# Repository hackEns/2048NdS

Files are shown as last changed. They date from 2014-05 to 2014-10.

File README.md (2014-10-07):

Nuit des Sciences 2014
======================

Codes, schematics etc. pour l'installation de LEDs (montage Ledhill) pour la Nuit des Sciences 2014 à l'Ens.

# Structure

* `frontend/`: web interface for playing, customized 2048 game to be used as a controller for the game server.
* `leds/`: code running on the ATmega on the LEDs PCB.
* `pc_control/`: python scripts to send instructions to the LEDs.
* `tests/`: various tests files for both the PCBs and the Serial comm in Python.

# Usage

* Launch `test_order.py` in the `tests` folder, to get the correct order in which LEDs should be controlled.
* Put the output of the previous command in the `get_linear_led_number` function in `pc_control/game.py` line 98 to set the correct order for the LEDs.
* Set the correct controller at the top of `pc_control/game.py`.
* Launch `leds_server.py` in the `pc_control` folder, on the computer connected to the LEDs using a USB FTDI cable. Pass the device `/dev/ttyUSB*` used to communicate with the LEDs as argument.
* Launch `game.py` in the `pc_control` folder passing it the server ip address as first argument. This can be launched on any computer as long as it can communicate with the previous one _via_ the port 4242 (or any other port, if you update the files `game.py` and `leds_server.py` accordingly).
* You are ready to go.

# License

All the source codes, unless explicitly specified otherwise are under the following license:

```
/*
 * --------------------------------------------------------------------------------
 * "THE NO-ALCOHOL BEER-WARE LICENSE" (Revision 42):
 * Phyks (webmaster@phyks.me) wrote or updated these files for hackEns. As long
 * as you retain this notice you can do whatever you want with this stuff
 * (and you can also do whatever you want with this stuff without retaining it,
 * but that's not cool...).
 *
 * If we meet some day, and you think this stuff is worth it, you can buy us a
 * <del>beer</del> soda in return.
 *                                                              Phyks for hackEns
 * ---------------------------------------------------------------------------------
 */
 ```

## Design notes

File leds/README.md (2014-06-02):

Used codes for ATMegas
======================

* `ATMegaBOOT.hex` is the bootloader burned on the ATMegas. It is a bit customized to avoid problems with Serial communication on startup.
* `dynamic/` is the code which uses the Serial communication between the LEDs. It was used for the 2048-like game on the 46 rue d'Ulm.
* `static/` is an autonomous code which can be launched on each LEDs without any special communication between them. It was used on the 45 rue d'Ulm.

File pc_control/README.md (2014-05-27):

PC Control of the LED for the 2048-like installation
====================================================

This is the code to run on the PC to control the LEDs.

It is composed of two modules:
* A game server `game.py` to handle the game and forge instructions for the LEDs.
* A LED server `leds_server.py` which waits for instructions and send them to the LEDs.

Both of them communicate _via_ the network. You should edit parameters in caps in the two previous files to match your configuration.

The game server uses a game controller to get events and update its status. These are located in `game_controllers/`. The most basic one is `KeyboardController` which simply listen for keypress on the arrow keys. It can be used as an example for more sophisticated one.

## Usage

1. Launch the LED server: `./leds_server.py SERIAL_PORT` where `SERIAL_PORT` is the one used to communicate with the LEDs.
2. Launch the game server: `./game.py HOST` where `HOST` is the host for the LED server.
3. Play

## Available controllers

Edit the `game.py` file to use the controller you want. By default, it uses the `KeyboardController`.

Available controllers are:
* `KeyboardController()` to control the game using the keyboard (and the arrow keys) on the game server.
* `WebController()` to display the 2048 web interface and control the game directly in the browser.

## License

```
/*
 * --------------------------------------------------------------------------------
 * "THE NO-ALCOHOL BEER-WARE LICENSE" (Revision 42):
 * Phyks (webmaster@phyks.me) wrote or updated these files for hackEns. As long
 * as you retain this notice you can do whatever you want with this stuff 
 * (and you can also do whatever you want with this stuff without retaining it, 
 * but that's not cool...).
 *
 * If we meet some day, and you think this stuff is worth it, you can buy us a 
 * <del>beer</del> soda in return.
 *                                                              Phyks for hackEns
 * ---------------------------------------------------------------------------------
 */
 ```

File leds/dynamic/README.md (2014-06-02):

Code running on ATmegas
====

Some notes on the PCBs and the code:

## Pins

* 15 (datasheet ATmel) == 9 (Arduino) : Led R
* 16 (datasheet ATmel) == 10 (Arduino) : Led G
* 17 (datasheet ATmel) == 11 (Arduino) : Led B

## Serial packets

A serial packet is as follow (4 bytes):

```
synchro (= 1) | function |  counter
 1bit         |  1 bit   |  6 bits
```

```
synchro (= 0) |  colorR
 1bit         |  7 bits
```

```
synchro (= 0) |  colorG
 1bit         |  7 bits
```

```
synchro (= 0) |  colorB
 1bit         |  7 bits
```

## Functions

* `0b0` : Immediate switch
* `0b1` : Broadcast (treat the packet but still forward it with null counter)

## Misc

* serialEvent is automatically called at the end of `loop()` if data is available on RX.
* When a header arrives, `serial_i = counter`
* `serial_i` describes the state:
    * `-1` => waiting for a header packet
    * `0` => waiting for data for red LED
    * `1` => waiting for data for blue LED
    * `2` => waiting for data for green LED
* No need to call `pinMode` before an `analogWrite`

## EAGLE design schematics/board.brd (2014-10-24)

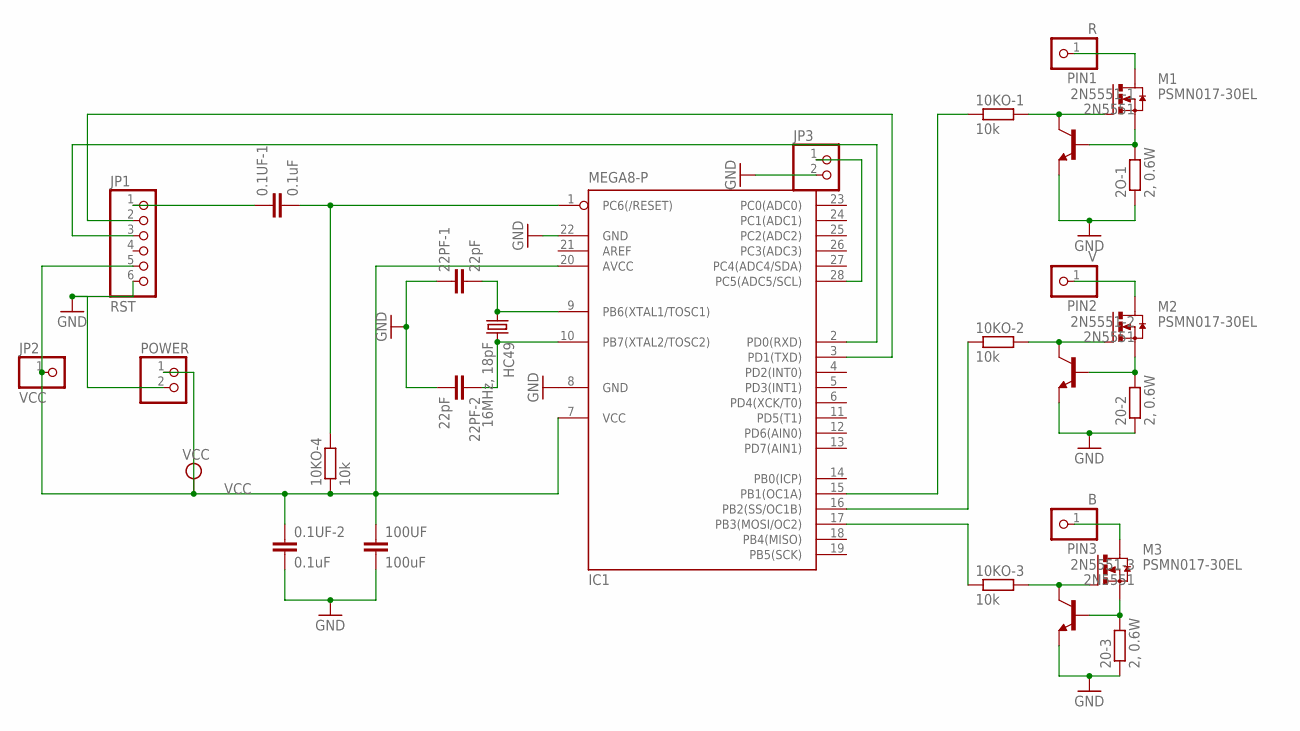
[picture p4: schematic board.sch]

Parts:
0.1UF-1, 0.1UF-2: 0.1uF; C025-030X050
2N5551-1, 2N5551-2, 2N5551-3: 2N5551; TO92-CBE
2O-1, 20-2, 20-3: 2, 0.6W; 0309V
10KO-1, 10KO-2, 10KO-3, 10KO-4: 10k; 0207/2V
22PF-1, 22PF-2: 22pF; C025-030X050
100UF: 100uF; C025-050X050
HC49: 16MHz, 18pF; HC49/S
IC1: MEGA8-P; DIL28-3
JP1: RST; 1X06
JP2: VCC; 1X01
JP3: PINHD-1X2; 1X02
M1, M2, M3: PSMN017-30EL; TO262-V
PIN1: R; 1X01
PIN2: V; 1X01
PIN3: B; 1X01
POWER: PINHD-1X2; 1X02

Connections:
GND: 0.1UF-2.2, 2N5551-1.E, 2N5551-2.E, 2N5551-3.E, 2O-1.1, 20-2.1, 20-3.1, 22PF-1.1, 22PF-2.2, 100UF.2, IC1.8 (GND), IC1.22 (GND), JP1.6, JP3.2, POWER.2
unnamed: 22PF-1.2, HC49.1, IC1.9 (PB6(XTAL1/TOSC1))
unnamed: 22PF-2.1, HC49.2, IC1.10 (PB7(XTAL2/TOSC2))
unnamed: 0.1UF-1.1, JP1.1
unnamed: 2N5551-2.C, 10KO-2.2, M2.1 (G)
unnamed: 0.1UF-1.2, 10KO-4.2, IC1.1 (PC6(/RESET))
unnamed: 2N5551-1.C, 10KO-1.2, M1.1 (G)
unnamed: 2N5551-2.B, 20-2.2, M2.3 (S)
unnamed: 2N5551-1.B, 2O-1.2, M1.3 (S)
unnamed: IC1.3 (PD1(TXD)), JP1.2
unnamed: 2N5551-3.C, 10KO-3.2, M3.1 (G)
unnamed: 2N5551-3.B, 20-3.2, M3.3 (S)
unnamed: IC1.2 (PD0(RXD)), JP1.3
unnamed: 10KO-1.1, IC1.15 (PB1(OC1A))
unnamed: 10KO-2.1, IC1.16 (PB2(SS/OC1B))
unnamed: 10KO-3.1, IC1.17 (PB3(MOSI/OC2))
unnamed: M1.2 (D), PIN1.1
unnamed: M2.2 (D), PIN2.1
unnamed: M3.2 (D), PIN3.1
unnamed: IC1.28 (PC5(ADC5/SCL)), JP3.1
VCC: 0.1UF-2.1, 10KO-4.1, 100UF.1, IC1.7 (VCC), IC1.20 (AVCC), JP1.5, JP2.1, POWER.1

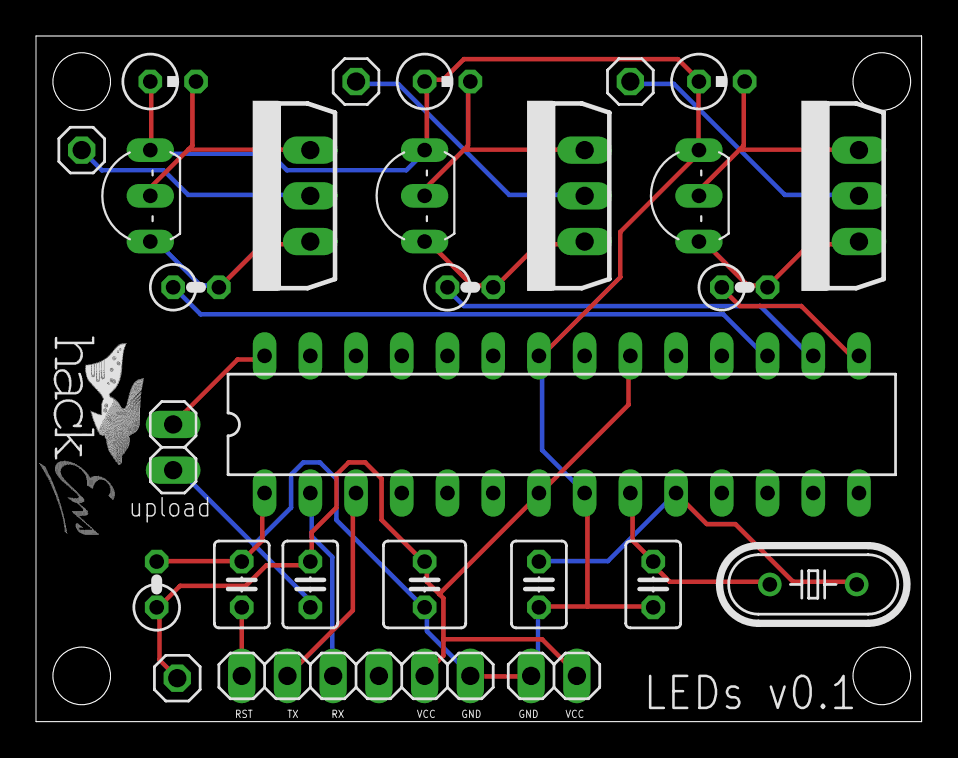
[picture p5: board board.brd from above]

Board: 2 copper layers, 49.2 x 38.1 mm, 28 parts (0 on the bottom side), 21 nets.

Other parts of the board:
U$1: HACKENS-LOGO

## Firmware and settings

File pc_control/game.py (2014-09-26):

#!/usr/bin/env python2
# -*- coding: utf8 -*-

# Code based on https://github.com/bfontaine/term2048
# Original license: MIT License, bfontaine:
#    https://github.com/bfontaine/term2048/blob/master/LICENSE

# Modifications licensed under:
# -----------------------------------------------------------------------------
# "THE NO-ALCOHOL BEER-WARE LICENSE" (Revision 42):
# Phyks (webmaster@phyks.me) wrote or updated these files for hackEns. As long
# as you retain this notice you can do whatever you want with this stuff
# (and you can also do whatever you want with this stuff without retaining it,
# but that's not cool...).
#
# If we meet some day, and you think this stuff is worth it, you can buy us a
# <del>beer</del> soda in return.
#                                                       Phyks for hackEns
# -----------------------------------------------------------------------------


import board
# Keyboard controller, uncomment to use
import game_controllers.keyboard_controller as ctrl

# Android controller, uncomment to use
# Use this code on the Android device :
# http://git.hackens.org/2048NdS_android_controller/
# import game_controllers.accelero_controller as ctrl

# Web controller, uncomment to use
# import game_controllers.web_controller as ctrl

# Joystick controller, uncomment to use
# import game_controllers.joystick_controller as ctrl

import json
import nick_selection
import predefined_colors as pc
import requests
import socket
import sys
import time
import tools

try:
    import secret
    api_key = secret.api_key
except:
    api_key = ''
    pass


class Game():
    """The class that handles the game itself and send instructions to the LEDs
    accordingly
    """
    COLORS = {
        0: pc.black,
        2: pc.yellow,
        4: pc.blue,
        8: pc.orange,
        16: pc.green,
        32: pc.red,
        64: pc.purple,
        128: pc.white,
        256: pc.rose,
        512: pc.skyblue
    }
    SCORES_FILE = "scores.dat"
    REMOTE_SCORES_URL = "http://hackens.org/NdS/"
    REMOTE_SCORES_PARAMS = {'api_key': api_key}

    def __init__(self, server_address, game_controller,
                 goal=256, size=3):
        self.brd = board.Board(goal=goal, size=size)
        self.score = 0
        self.server_address = server_address
        self.game_controller = game_controller()
        self.size = size

    def __enter__(self):
        return self

    def end(self):
        """Returns True if the game is finished"""
        return (self.brd.won() or not self.brd.can_move())

    def update_score(self, points):
        """Updates the current score adding it the specified
        amount of points
        """
        self.score += points

    def get_linear_led_number(self, x, y):
        """Returns the led number, position in the linear chain, to send the
        number to the LED server"""
        pos = [[7, 8, 1], [6, 0, 2], [5, 4, 3]]
        return pos[x][y]

    def save_score(self):
        """Saves the current score"""
        nick = nick_selection.get_nick()
        with open(self.SCORES_FILE, 'a') as fh:
            fh.write(nick+"\t"+str(self.score))
        # Send to remote server
        params = self.REMOTE_SCORES_PARAMS
        params["do"] = "add"
        params["nick"] = nick
        params["score"] = self.score
        try:
            r = requests.get(self.REMOTE_SCORES_URL, params=params)
            if r.status_code != 200 or 'ack' not in r.text:
                tools.error("Unable to post high score.")
        except requests.exceptions.ConnectionError as e:
            tools.error("Network error when submitting high score:"+str(e))

    def won_animation(self):
        """Handle the animation when the player wins"""
        # Go to rose
        self.send_instructions({'fading': True,
                                'fading_duration': 3,
                                'colors': {i: pc.rose
                                           for i in range(self.size**2)}
                                })
        # Wait 3s
        time.sleep(6)
        # Go to black
        self.send_instructions({'fading': True,
                                'fading_duration': 3,
                                'colors': {i: pc.black
                                           for i in range(self.size**2)}
                                })
        # Wait 7s
        time.sleep(2)
        # Go to green
        self.send_instructions({'fading': True,
                                'fading_duration': 3,
                                'colors': {i: pc.green
                                           for i in range(self.size**2)}
                                })

    def game_over_animation(self):
        """Handle the animation when the player looses"""
        # Go to rose
        self.send_instructions({'fading': True,
                                'fading_duration': 3,
                                'colors': {i: pc.rose
                                           for i in range(self.size**2)}
                                })
        # Wait 3s
        time.sleep(6)
        # Go to black
        self.send_instructions({'fading': True,
                                'fading_duration': 3,
                                'colors': {i: pc.black
                                           for i in range(self.size**2)}
                                })
        # Wait 7s
        time.sleep(2)
        # Go to red
        self.send_instructions({'fading': True,
                                'fading_duration': 3,
                                'colors': {i: pc.red
                                           for i in range(self.size**2)}
                                })

    def get_diff(self):
        """Returns the difference between previous and current state"""
        data = {"fading": False, "colors": {}}
        data["colors"] = {self.get_linear_led_number(k['x'], k['y']):
                          self.COLORS[k["value"]]
                          for k in self.brd.get_diff()}
        return data

    def initialize_leds(self):
        """Returns a dict with the default color to send to the LEDs with
        send_instructions()
        """
        return {"fading": False, "colors": {k: self.COLORS[0] for k in
                                            xrange(self.size**2)}}

    def send_instructions(self, data):
        """Sends instructions to the LEDs server to display the current
        configuration

        params:
            data is a dict {fading: bool, colors: {}}, cf get_diff
        """
        if len(data["colors"]) == 0:
            return

        sock = socket.socket(socket.AF_INET, socket.SOCK_STREAM)

        try:
            sock.connect(self.server_address)
            data = json.dumps(data) + "\n"
            sock.sendall(data)
            received = sock.recv(1024)
            try:
                if int(received) != len(data.strip()):
                    tools.error("Error while sending instructions for LEDs")
            except:
                tools.error("Error while sending instructions for LEDs")
        finally:
            sock.close()

    def readMove(self):
        """Reads the move from the controller and
        maps it to Board.{UP,DOWN,LEFT,RIGHT}
        """
        m = self.game_controller.get()
        if m == "LEFT":
            return board.Board.LEFT
        elif m == "RIGHT":
            return board.Board.RIGHT
        elif m == "UP":
            return board.Board.UP
        elif m == "DOWN":
            return board.Board.DOWN
        else:
            return 0

    def current_status(self):
        tmp = self.brd.current_status()
        out = {}
        for coords in tmp:
            out[self.get_linear_led_number(coords[0], coords[1])] = self.COLORS[tmp[coords]]
        return out

    def loop(self):
        """Main loop"""
        self.send_instructions(self.initialize_leds())
        while True:
            if self.end():
                break
            self.send_instructions(self.get_diff())
            m = self.readMove()
            self.update_score(self.brd.move(m))
            self.brd.print_brd()
        print("Valeur la plus élévée: "+str(self.brd.max_tile()))

        for i in range(3):
            self.send_instructions({'fading': False,
                                    'colors': {i: pc.black
                                               for i in range(self.size**2)}
                                    })
            time.sleep(0.1)
            self.send_instructions({'fading': False,
                                    'colors': self.current_status()})
            time.sleep(0.5)

        if self.brd.won():
            print('You won')
            self.won_animation()
        else:
            print('Game over')
            self.game_over_animation()
        self.save_score()
        return self.score

    def close(self):
        """Handle the cleaning, if necessary"""
        if hasattr(self.game_controller, 'close'):
            self.game_controller.close()

    def __exit__(self, type, value, traceback):
        self.close()


if __name__ == "__main__":
    if len(sys.argv) < 2:
        tools.error("Usage: "+sys.argv[0]+" SERVER_IP")
        sys.exit(1)
    HOST = sys.argv[1]
    PORT = 4242

    try:
        while True:
            print("Let's go !")
            with Game((HOST, PORT), ctrl.Controller) as game:
                print("Score " + str(game.loop()))
    except KeyboardInterrupt:
        print("\nExit…")
        sys.exit()

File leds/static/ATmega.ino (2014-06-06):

/* This code runs on the LEDs PCB and handles the serial communication and
 * correct colors display.
 *
 * --------------------------------------------------------------------------------
 * "THE NO-ALCOHOL BEER-WARE LICENSE" (Revision 42):
 * Phyks (webmaster@phyks.me) wrote or updated these files for hackEns. As long
 * as you retain this notice you can do whatever you want with this stuff 
 * (and you can also do whatever you want with this stuff without retaining it, 
 * but that's not cool...).
 *
 * If we meet some day, and you think this stuff is worth it, you can buy us a
 * <del>beer</del> soda in return.
 *                                                              Phyks for hackEns
 * ---------------------------------------------------------------------------------
 */
#include <math.h>
#define R 0
#define G 1
#define B 2

struct RGBColor {
    int r;
    int g;
    int b;
};

struct RGBColorFloat {
    float r;
    float g;
    float b;
};

struct HSVColor {
    float h;
    float s;
    float v;
};

const struct RGBColor red = {255, 0, 0};
const struct RGBColor rose = {232, 30, 116};
const struct RGBColor black = {0, 0, 0};
const struct RGBColorFloat corrections = {0.863, 1, 0.863};
const int pins[3] = {9, 10, 11};


struct HSVColor rgb255_to_hsv(struct RGBColor color_in) {
    RGBColorFloat color = {float(color_in.r) / 255, float(color_in.g) / 255, float(color_in.b) / 255};
    HSVColor color_out = {0, 0, 0};

    float M = max(color.r, max(color.g, color.b));
    float m = min(color.r, min(color.g, color.b));

    if(m == M) {
        color_out.h = 0.0;
    }
    else if(M == color.r) {
        color_out.h = fmod(60 * (color.g - color.b) / M - m + 360, 360);
    }
    else if(M == color.g) {
        color_out.h = (60 * (color.b - color.r) / M - m + 120);
    }
    else if(M == color.b) {
        color_out.h = (60 * (color.r - color.g) / M - m + 240);
    }

    if(M == 0.0) {
        color_out.s = 0.0;
    }
    else {
        color_out.s = 1 - m / M;
    }

    color_out.v = M;

    return color_out;
}


RGBColor hsv_to_rgb255(HSVColor color) {
    int qd = int(color.h / 60) % 6;
    float f = color.h / 60 - qd;
    float l = color.v * (1 - color.s);
    float m = color.v * (1 - f * color.s);
    float n = color.v * (1 - (1 - f) * color.s);
    RGBColor color_out = {0, 0, 0};

    switch(qd) {
        case 0:
            color_out.r = 255*color.v;
            color_out.g = 255*n;
            color_out.b = 255*l;
            break;

        case 1:
            color_out.r = 255*m;
            color_out.g = 255*color.v;
            color_out.b = 255*l;
            break;

        case 2:
            color_out.r = 255*l;
            color_out.g = 255*color.v;
            color_out.b = 255*n;
            break;

        case 3:
            color_out.r = 255*l;
            color_out.g = 255*m;
            color_out.b = 255*color.v;
            break;

        case 4:
            color_out.r = 255*n;
            color_out.g = 255*l;
            color_out.b = 255*color.v;
            break;

        case 5:
            color_out.r = 255*color.v;
            color_out.g = 255*l;
            color_out.b = 255*m;
            break;
    }
    return color_out;
}


void show_color(RGBColor color) {
    analogWrite(pins[R], (int) (color.r * corrections.r));
    analogWrite(pins[G], (int) (color.g * corrections.g));
    analogWrite(pins[B], (int) (color.b * corrections.b));
}


void fading(RGBColor src_color, RGBColor dest_color, int nb_steps) {
    HSVColor src_color_hsv = rgb255_to_hsv(src_color);
    HSVColor dest_color_hsv = rgb255_to_hsv(dest_color);
    HSVColor current_color = {0, 0, 0};

    float step_size_h = float(dest_color_hsv.h - src_color_hsv.h) / nb_steps;
    float step_size_s = float(dest_color_hsv.s - src_color_hsv.s) / nb_steps;
    float step_size_v = float(dest_color_hsv.v - src_color_hsv.v) / nb_steps;

    for(int i = 0; i < nb_steps + 1; i++) {
        current_color.h = src_color_hsv.h + i * step_size_h;
        current_color.s = src_color_hsv.s + i * step_size_s;
        current_color.v = src_color_hsv.v + i * step_size_v;
        show_color(hsv_to_rgb255(current_color));
        delay(40);
    }
}


void setup() {
    show_color(red);
    randomSeed(analogRead(0));
    delay(1000);
    show_color(black);
}

void loop() {
    int rand_fading_duration = random(60);
    int rand_duration = random(60, 180);

    fading(black, rose, 25*rand_fading_duration);
    delay(rand_duration*1000);
    rand_fading_duration = random(60);
    fading(rose, black, 25*rand_fading_duration);
    rand_duration = random(60, 180);
    delay(rand_duration*1000);
}

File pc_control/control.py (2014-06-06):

# -*- coding: utf8 -*-

# -----------------------------------------------------------------------------
# "THE NO-ALCOHOL BEER-WARE LICENSE" (Revision 42):
# Phyks (webmaster@phyks.me) wrote or updated these files for hackEns. As long
# as you retain this notice you can do whatever you want with this stuff
# (and you can also do whatever you want with this stuff without retaining it,
# but that's not cool...).
#
# If we meet some day, and you think this stuff is worth it, you can buy us a
# <del>beer</del> soda in return.
#                                                       Phyks for hackEns
# -----------------------------------------------------------------------------

import colors
import serial
import time
import tools


class Control():
    """Class to control the LEDs by sending instructions over serial.

    All colors are RGB in [0,255] but we have to send values between [0,127]
    to the LEDs.
    """
    def __enter__(self):
        return self

    def __init__(self, serial_port, nb_leds,
                 corrections={'r': 1.0, 'g': 1.0, 'b': 1.0},
                 brightness=1.0,
                 nb_steps_fading=25):
        """Params:
            * ser is an open pySerial object
            * nb_leds is the total number of LEDs
            * corrections is used to correct the differences between colors
            intensity
            * brightness is used to reduce the global brightess
            * nb_steps_fading is the number of steps to use by default for
            fading
        """
        self.corrections = {k: float(brightness) * corrections[k]
                            for k in corrections}

        self.serial_port = serial_port
        self.ser = serial.Serial(port=self.serial_port, baudrate=115200)
        if not self.ser.isOpen():
            try:
                self.ser.open()
            except Exception, e:
                tools.error("Error opening serial port: " + str(e))
        if not self.ser.isOpen():
            tools.error("Serial port not opened")
        self.ser.flushInput()
        self.ser.flushOutput()

        self.nb_leds = nb_leds
        self.nb_steps_fading = nb_steps_fading
        self.current_colors = [{'r': 255, 'g': 0, 'b': 0}
                               for i in xrange(nb_leds)]

    def get_current_colors(self, id=None):
        """Returns the current colors of the LEDs, as a list"""
        if id is None:
            return self.current_colors
        else:
            return self.current_colors[id]

    def correct_color(self, color):
        """Corrects the color to match real LED render, applying `corrections`

        params: color a {r, g, b} dict
        returns: a color dict
        """
        return {i: int(color[i] * self.corrections[i]) >> 1 for i in color}

    def send_color(self, id, color, fading=False, fading_duration=1):
        """Corrects the color and send it over serial

        Params:
            * id is the id of the LED to address
            * color is a RGB255 color dict
            * fading_duration is the total duration of the fading

        If fading is passed and is not false, interpolates to do a fading
        between current and dest color. Fading can be an int to bypass the
        default number of intermediate steps or just True.
        """
        data = []
        id = int(id)
        if fading is not False:
            if isinstance(fading, (int, long)):
                steps = colors.fading(self.current_colors[id],
                                      color,
                                      fading)
                wait = float(fading_duration) / fading
            else:
                steps = colors.fading(self.current_colors[id],
                                      color,
                                      self.nb_steps_fading)
                wait = float(fading_duration) / self.nb_steps_fading
        else:
            steps = [color]
            wait = 0

        for step in steps:
            data += [0x80 + id]
            tmp_color = self.correct_color(step)
            data.append(tmp_color['r'])
            data.append(tmp_color['g'])
            data.append(tmp_color['b'])

        for i in xrange(len(data)):
            self.ser.write(chr(data[i]))
            if i % 4 == 0:
                time.sleep(wait)
        self.current_colors[id] = color

    def send_colors(self, colors_in, starting=0, fading=False,
                    fading_duration=1.0):
        """Send colors instruction to a bunch of LEDs

        Params:
            * colors_in is a list of color dicts for each LEDs
            * starting is the index of the first LED to control
            * fading, see send_color()
            * fading_duration is the total duration of the fading
        """
        if fading is not False:
            if fading is not True and isinstance(fading, (int, long)):
                steps = {int(id): colors.fading(self.current_colors[int(id)],
                                                colors_in[id],
                                                fading)
                         for id in colors_in}
                wait = 1.0 / fading
            else:
                steps = {int(id): colors.fading(self.current_colors[int(id)],
                                                colors_in[id],
                                                self.nb_steps_fading*fading_duration)
                         for id in colors_in}
                wait = 1.0 / self.nb_steps_fading
        else:
            steps = {int(id): [colors_in[id]] for id in colors_in}
            wait = 0

        for k in xrange(len(steps[steps.iterkeys().next()])):
            for i in steps:
                # Send the color to the individual LED, and duration is 0 as
                # it is handled inside this function (globally and not per LED)
                if i + starting > self.nb_leds:
                    continue  # No need to send useless data
                self.send_color(i + starting, steps[i][k], fading_duration=0)
            time.sleep(wait)

    def reset(self):
        """Resets all the LEDs to red, default state after setup()"""
        for k in range(self.nb_leds):
            for i in [0x80 + k, 127, 0, 0]:
                self.ser.write(chr(i))

    def close(self):
        """Closes the serial communication"""
        if self.ser.isOpen():
            self.ser.close()

    def __exit__(self, type, value, traceback):
        self.close()

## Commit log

2014-05-20 * Code des LEDs * Début du code de contrôle
2014-05-22 LED control
2014-05-22 2048 board class
2014-05-24 LED server should be ok
    Code is composed of two modules :
    * A LED server which receive instructions and forward them to the LEDs
    * A game server which handles the gaming and sends instructions
    accordingly to the LED server.
2014-05-25 Game server + LED server improved
    * Bugfixes
    TODO : get_diff not working + error in send_colors
    [board.py, control.py, game.py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]
2014-05-25 LED server working
2014-05-26 PEP8 + requests error handling
    [board.py, colors.py, control.py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]
2014-05-29 Controller for the accelerometer app on smartphone
2014-06-02 Default port pour acceleromètre
2014-06-02 Created a static code for the LED on 45 rue d'Ulm
2014-06-03 No threading to respect timing
2014-06-05 Animations pour les LEDs du 45
2014-06-05 Bugfix in static leds code
    [ATmega.ino]
2014-06-05 Bugfix in 45 + test_correction
    [ATmega.ino, test_correction.ino]
2014-06-05 Bugfix in test serial
    [test_serial.py]
2014-06-05 Rebug fix in test_serial
    [test_serial.py]
2014-06-06 Script pour corriger les LEDs
    [test_corrections.py]
2014-06-06 Updated corrections for the LEDs
    [ATmega.ino, leds_server.py, visualizer.py]
2014-06-06 Ordre des LEDs
2014-06-06 Fix numerotation des leds
    [game.py, nick_selection.py]
2014-06-06 Mauvais ordre pour l'envoi de couleurs
2014-06-06 Animations de fin
2014-06-06 Shorter dark duration on lose/win anim
    [game.py]
2014-06-06 nick à la fin
2014-06-06 Anim de fin
2014-09-25 Add a simple test for checking LEDs order
2014-10-24 EAGLE schematics (WIP)
    [board.brd, board.sch]
2014-10-24 Ajoute alim & logo sur la PCB
    [board.brd, board.sch]
2014-10-24 Bigger logo
    [board.brd]
2014-10-24 Ajout pins upload
    [board.brd, board.sch]
2014-10-24 Connecte AVCC et VCC
    D'après la datasheet atmel
    (http://www.farnell.com/datasheets/1698185.pdf )
    [board.brd, board.sch]
